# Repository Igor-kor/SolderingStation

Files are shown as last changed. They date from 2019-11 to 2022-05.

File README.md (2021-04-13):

# Паяльный фен
 Основные компоненты:
- Arduino uno
- Операционный усилитель lm358p
- Симистор bt139
- Отопара moc3021
- Источник питаниям 5 вольт и 24 вольта
- OLED дисплей I2C SSD1306
- Энкодер 
- irfz44n для управления скоростью потока воздуха
- ltv814 (2) оптопара для определения перехода через 0, и (для этого можно заменить на ltv817) для включения irfz44n

Используемые библиотеки:
- для дисплея https://github.com/olikraus/u8g2
- библиотека пид регулятора https://playground.arduino.cc/Code/PIDLibrary/
- ускоренное ядро ардуино https://github.com/AlexGyver/GyverCore

Полезная информация
- по настройке коэфициентов пид регулятора http://lazysmart.ru/osnovy-avtomatiki/nastrojka-pid-regulyatora/
- дискретный регулятор мощности (теория, как в итоге должно работать) https://www.qrz.ru/schemes/contribute/digest/bp169.shtml

В собраном виде
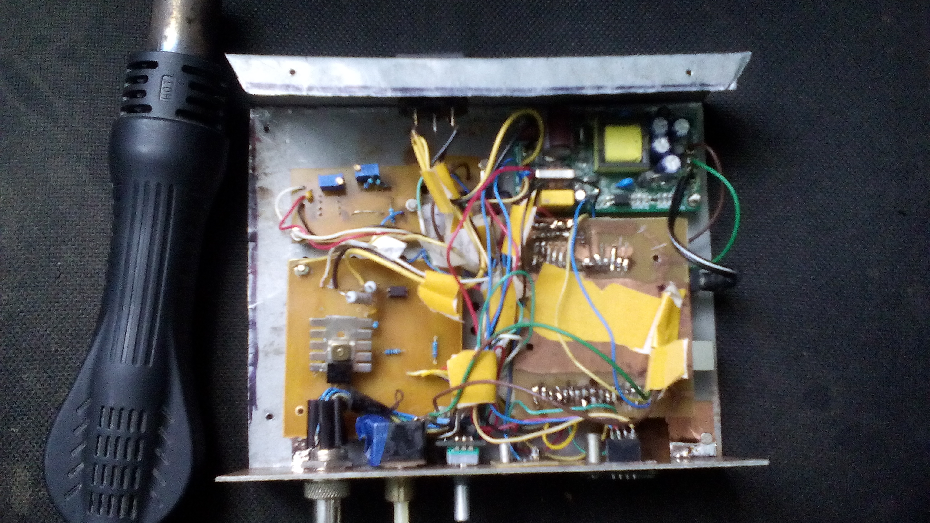
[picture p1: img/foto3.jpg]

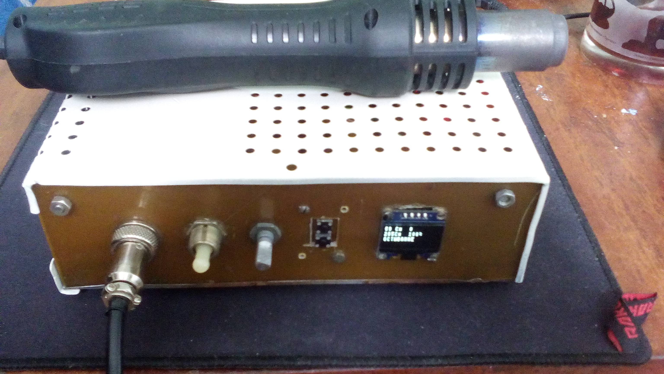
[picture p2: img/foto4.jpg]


Для правильной регулировки написал программу на C# показывающую график https://github.com/Igor-kor/ArduinoDiagramm
- Пример
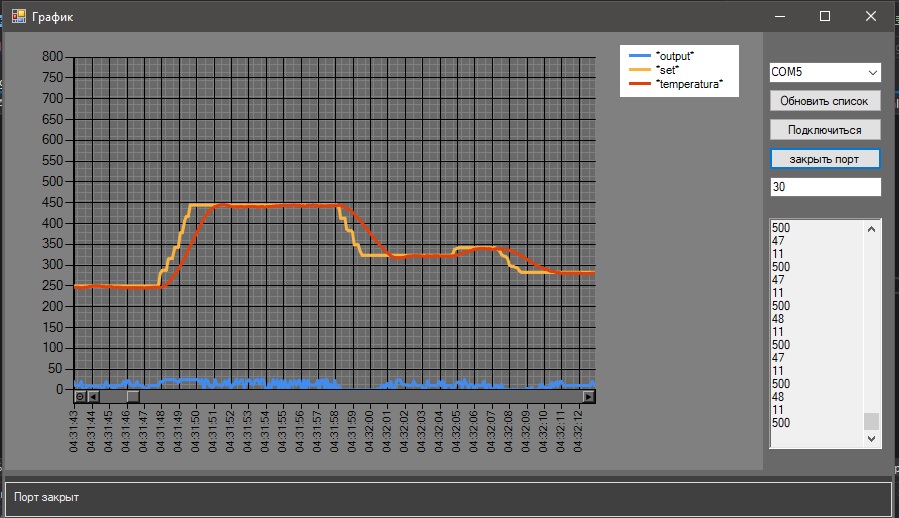
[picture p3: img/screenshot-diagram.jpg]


Схемы
- Определение перехода через 0
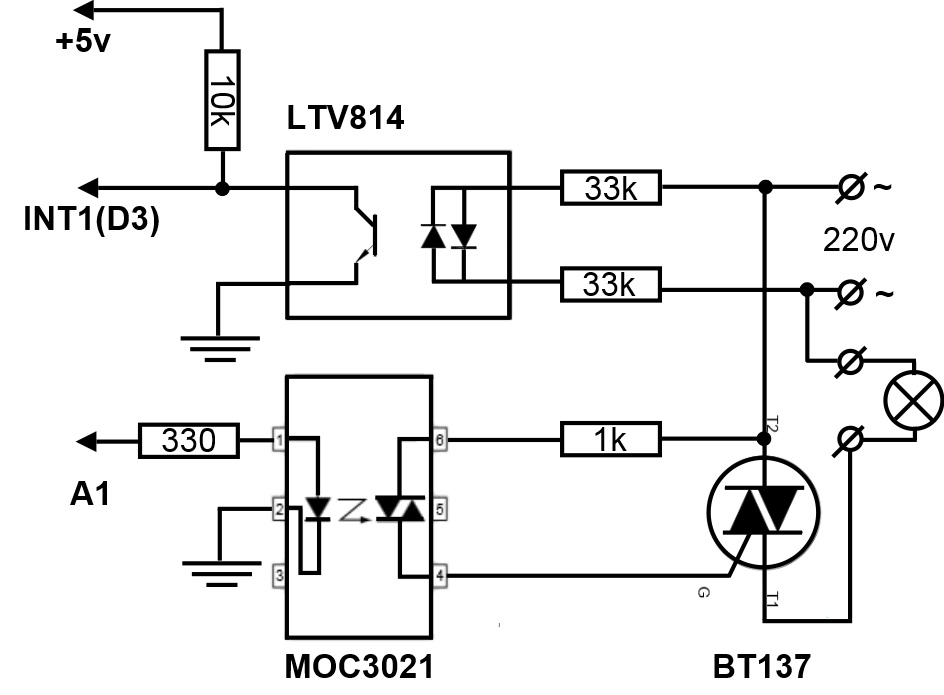
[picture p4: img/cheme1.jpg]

- Управление турбиной фена
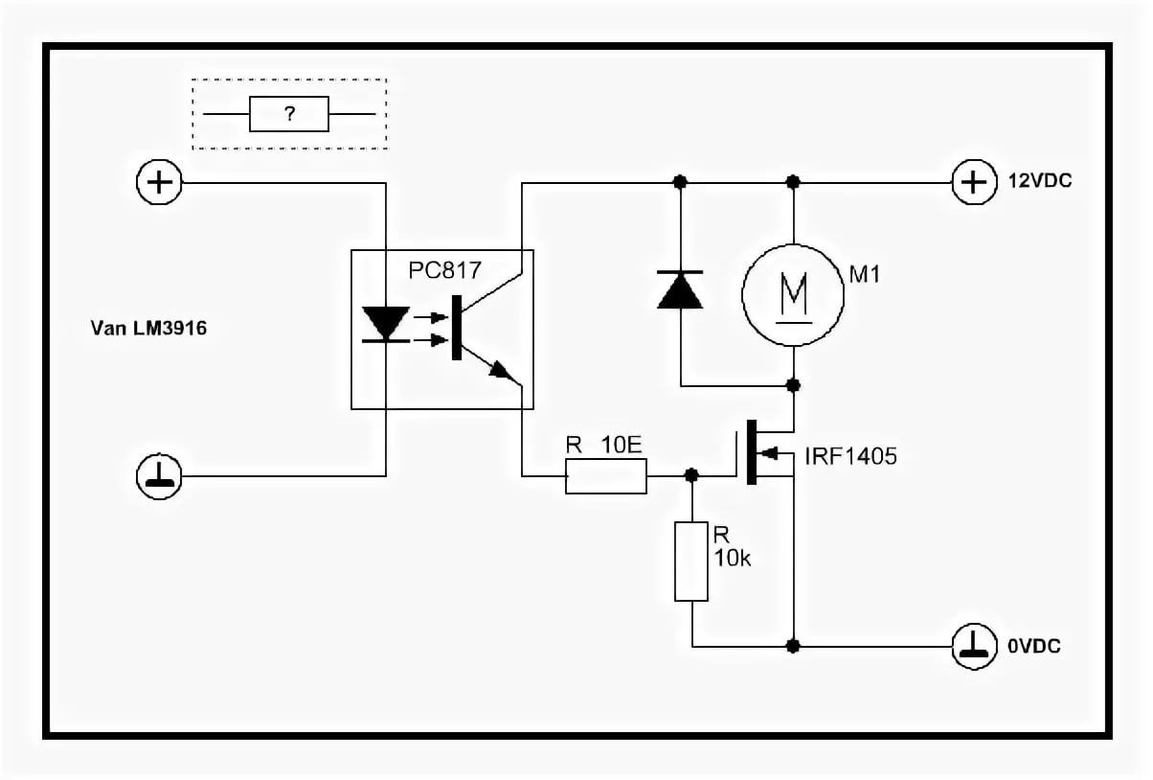
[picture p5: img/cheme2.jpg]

- Усилитель для термопары
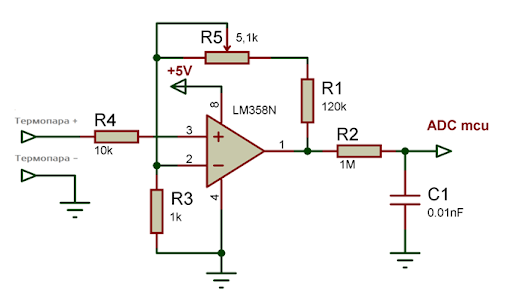
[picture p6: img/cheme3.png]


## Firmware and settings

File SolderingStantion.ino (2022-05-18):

#include <Arduino.h>
#include <U8g2lib.h>

//#define DEBAGSERIAL
//#define DEBAGPIDSERIAL
// Language and font
#include "u8x8_font_ikor.h"
#include "rus.h"
//#include "eng.h"

#include "Thermofan.h"

U8X8_SSD1306_128X32_UNIVISION_HW_I2C u8x8(/* clock=*/ SCL, /* data=*/ SDA, /* reset=*/ U8X8_PIN_NONE);
unsigned long lastTickEncoder;
bool encDirection = 0;
int encCounter = 0;
bool echoEncoder = true;
bool state0, lastState, turnFlag = false;
//uint32_t mil = 0; //текущие милисекунды для вывода на экран
int countzerocross = 0;
int warmcount = 10;
bool statewarm = false;
bool oldstatewarm = false;
// PID
double KP = 7, KI = 5, KD = 0.1;
Thermofan* thermofan1;

void setup() {
  Serial.begin(9600);
#ifdef DEBAGSERIAL
  Serial.println("Setup SolderingStantion.ino");
#endif
  u8x8.begin();
  u8x8.setPowerSave(0);
  u8x8.setFont(u8x8_font_ikor);
  thermofan1 =  new Thermofan();
  attachInterrupt(1, Thermofan::attachCrossZero, FALLING);
  attachInterrupt(0, Thermofan::attachEncoder, CHANGE);

  // инициализация Timer2
    cli(); // отключить глобальные прерывания
    TCCR2A = 0; // установить TCCR1A регистр в 0
    TCCR2B = 0;

    // включить прерывание Timer2 overflow:
    TIMSK2 = (1 << TOIE2);
    // Установить CS10 бит так, чтобы таймер работал при тактовой частоте:
    TCCR2B |= (1 << CS10);
    sei(); // включить глобальные прерывания
#ifdef DEBAGSERIAL
  Serial.println("end Setup SolderingStantion.ino");
#endif
}

ISR(TIMER2_OVF_vect)
{
   Thermofan::attachFun();
}

void loop() {
  #ifdef DEBAGSERIAL
  Serial.println("Loop SolderingStantion.ino");
#endif 
  thermofan1->loopth();
    #ifdef DEBAGSERIAL
  Serial.println("End Loop SolderingStantion.ino");
#endif
}

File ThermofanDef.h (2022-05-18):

#ifndef THERMOFANDEF_H
#define THERMOFANDEF_H

#define VERSION "1.4.4"

//Максимальная температура на потенциометре
#ifndef TEMP_MAX
#define TEMP_MAX 600
#endif

//Температура при достижении которой отключится нагрев(для аварийного охлаждения);
#ifndef TEMP_MAX_OFF
#define TEMP_MAX_OFF 600
#endif

//Температура после которой фен снова начнет свою работу после аварийного охлаждения
#ifndef TEMP_MIN_ON
#define TEMP_MIN_ON 80
#endif

// Время вывода мс(вывод на дисплей сильно замедляет ардуину)
#ifndef TIME_ECHO
#define TIME_ECHO 100
#endif

// примерно 500 тиков совершает между переходом через 0
#ifndef WARMTICK
#define WARMTICK 500
#endif

// для энкодера
#ifndef ENC_LEFT
#define ENC_LEFT 1
#endif

#ifndef ENC_RIGHT
#define ENC_RIGHT 0
#endif

#ifndef MILLIS_CHANGE_DIRECTION
#define MILLIS_CHANGE_DIRECTION 100
#endif

// пин энкодера
#ifndef ENC_A
#define ENC_A 2
#endif

// пин энкодера
#ifndef ENC_B
#define ENC_B 4
#endif

// тип энкодера, 0 или 1
#ifndef ENC_TYPE
#define ENC_TYPE 1
#endif

// Пин термопары(операционного усилителя)
#define THERMOCOUPLE_PIN A0
// Пин оптопары нагрева фена
#define OPTRON_PIN 9
#define SPEED_FAN_PIN 5

#endif

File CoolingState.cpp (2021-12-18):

#include "State.h"
#include "Thermofan.h"
#include "CoolingState.h"
#include "WarmingState.h"
#include "WaitingState.h"
#include "SettingState.h"

extern U8X8_SSD1306_128X32_UNIVISION_HW_I2C u8x8;
extern unsigned long lastTickEncoder;
extern bool encDirection;
extern int encCounter;
extern bool echoEncoder;
extern bool state0, lastState, turnFlag;
extern int countzerocross;
extern int warmcount;
extern bool statewarm;
extern bool oldstatewarm;

CoolingState::CoolingState(Thermofan* context) : State(context) {
#ifdef DEBAGSERIAL
  Serial.println("CoolingState::CoolingState");
#endif
  u8x8.clearLine(2);
  context->echoDisplay("\x9e\xa1\xa2\xab\x92\x90\x9d\x98\x95", 2, 0);
}

void CoolingState::loop() {
#ifdef DEBAGSERIAL
  Serial.println(" CoolingState::loop()");
#endif
  // если температура меньше 50 градусов то перейдем в состояние ожидания
  if (context->Input < 50) {
    context->speedfan = context->echospeedfan;
    echoEncoder = true;
    context->SetState(new WaitingState(context));
    return;
  }
  // если нагрев включили то переходим в состояние нагрева
  if (!context->hermeticContactState) {
    context->speedfan = context->echospeedfan;
    echoEncoder = true;
    context->SetState(new WarmingState(context));
    return;
  }
  warmcount = 0;
  if(context->speedfan != 100) {
     echoEncoder = true;
  }
  context->speedfan = 100;
}

CoolingState::~CoolingState() {
}

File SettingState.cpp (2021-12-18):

#include "State.h"
#include "Thermofan.h"
#include "CoolingState.h"
#include "WarmingState.h"
#include "WaitingState.h"
#include "SettingState.h"

extern U8X8_SSD1306_128X32_UNIVISION_HW_I2C u8x8;
extern unsigned long lastTickEncoder;
extern bool encDirection;
extern int encCounter;
extern bool echoEncoder;
extern bool state0, lastState, turnFlag;
extern int countzerocross;
extern int warmcount;
extern bool statewarm;
extern bool oldstatewarm;
extern double KP,KI,KD;

SettingState::SettingState(Thermofan* context) : State(context) {
#ifdef DEBAGSERIAL
  Serial.println("WaitingState::WaitingState");
#endif
  u8x8.clearLine(2);
  context->echoDisplay(S_SETTING, 2, 0);
  this->oldButtonChange = context->encButtonChange;
}
void SettingState::loop() {
#ifdef DEBAGSERIAL
  Serial.println("SettingState::loop");
#endif
  // если нагрев включили то переходим в состояние нагрева
  if (!context->hermeticContactState) {
    context->speedfan = context->echospeedfan;
    context->SetState(new WarmingState(context));
    echoEncoder = true;
    return;
  }
  warmcount = 0;
  if (context->speedfan > 0) {
    echoEncoder = true;
  }
  context->speedfan = 100;
}

void SettingState::encoder() {
  if (context->encButtonChange != this->oldButtonChange) {
    this->oldButtonChange = context->encButtonChange;
    this->Ksave++;
    if(this->Ksave>2)
      this->Ksave=0;
  }  
   u8x8.clearLine(3);
  switch(this->Ksave){
    case 0:
        KP += encCounter/100.0;
        context->echoDisplay(String("P"), 3, 7);
        context->echoDisplay(String(KP,3), 3, 0);
      break;
    case 1:
        KI += encCounter/100.0;
        context->echoDisplay(String("I"), 3, 7);
        context->echoDisplay(String(KI,3), 3, 0);
      break;
    case 2:
        KD += encCounter/100.0;
        context->echoDisplay(String("D"), 3, 7);
        context->echoDisplay(String(KD,3), 3, 0);
      break;
  }
}

SettingState::~SettingState() {
}

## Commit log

2018-02-18 не рабочая плата, и прошивка не доработана инит коммит
    [stantion.sch]
2018-02-18 начал переделывать схему
2018-03-19 сделал класс термофена
2018-05-22 немного отрефакторил
2018-09-17 добаил реле на 4 пин
2019-11-08 добавил lcd экран и немного отрефакторил
2019-11-09 небольшие правки
2019-11-10 вынес класс в отдельный файл, оптимизировал вывод, вернул старые значения пид
2019-11-12 пофиксил нагрев во время вывода на дисплэй
2019-11-12 тест обновления экрана только при изменении(не работает т.к. экран очищается спустя секнду)
2019-11-12 вернул как было и убрал автообновление экрана
2019-11-12 пофиксил названия класса и инклуда
2019-11-12 рефакторинг и фикс бага при отключении нагрева this->warmingFan
2019-11-12 добавил ошибки и обработчик на ошибку 1( перегрев фена)
2019-11-12 изменил название stantion.ino на SolderingStation.ino
2019-11-12 изменил описание в readme
2019-11-13 переименовал на правильное название
2019-11-18 удалил старые схемы, добавил новые,для нагрева работает на текущий момент(без определения перехода через 0), вторую схему(для оу) не проверял
    [stantion.sch]
2019-11-18 добаивл схему для определения перехода через 0(не уверен что разводка по этой схеме)
2019-12-18 добавил оптопару для определения перехода фазы через 0, переделал нагрев фена(тест)
2020-01-06 сделал схему для управлением потока воздуха, и в коде для теста, нужен потенциометр
2020-02-09 обновил рэдми
2020-02-14 сделал рабочий энкодер
2020-02-14 рефакторинг
2020-02-15 сделал кнопку энкодера и смену выбора значений(температура-скорость потока)
2020-02-15 сделал управление потоком воздуха с энкодера
2020-02-15 пофиксил управление потоком воздуха
2020-02-20 Сделал энкодер более стабильным, сделал сохранения в eeprom установленных значений при нажатии на энкодер
2020-02-22 поменял направление энкодера
2020-03-02 исправлены ошибки в разводке плат, добавлена схема управления вентилятором
2020-03-02 изменил методику нагрева, частично пофиксил баг при включении, изменил пид коэфициенты
2020-03-03 добавил отдельную кнопку сохранения
2020-03-05 добавил кнопки и плату для них
2020-06-24 мелкие правки
2020-07-24 добавил корректировку температуры,присутствует проблема - после 370 градусов, фен начинает бесконтрольно нагреваться до предела
2020-07-27 на + термапары припаял резистор 10 КОм, сделал калибровку пида, уменьшил интервал просчета пида, изменил корректировку, сделал больше число для регулировки(WARMTICK)
2020-07-28 создал папку img, добавил изображения, обновил редми
2021-03-09 вынес пины в макросы, оптимизировал функцию нагрева, немного оптимизировал вывод на дисплей(нужно еще больше оптимизировать)
2021-03-10 переделал функцию энкодера, при быстром вращении теперь больше прибавляет
2021-03-10 нужно исправить баг с нагревом
    [ThermofanDef.h]
2021-03-11 перенастраиваю пид, сделал остывание фена и выключение турбины
2021-03-29 вынес все классы в отдельные файлы, реализацию в cpp файлы, делаю шаблон состояния
2021-04-08 промежуточный коммит
2021-04-13 доделал состояния, необходимо пофиксить баг с переходом, вполне рабочий коммит
2021-04-13 немного пофиксил баг, но не до конца
2021-04-13 чуть лучше чем было но баг с зависанием остался
2021-04-14 fix display cirilic text
    [CoolingState.cpp, SolderingStantion.ino, WaitingState.cpp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]
2021-04-14 переделываю энкодер, есть баг с сохранением скорости фена
2021-08-11 пофиксил баг в выводе скоросте фена, баг в сохранении скорости фена, баг в коде в присвоении и в условии
2021-08-11 пофиксил баг с охлаждением
2021-08-11 переделал изменение скорости фена, и пофиксил баг с сохранением скорости
2021-08-11 убрал лишнее
2021-12-17 Изменил переменные для времени
2021-12-17 Пофиксил баг при долгом ожидании
2021-12-18 add class settingstate, add version for reset eeprom
    [CoolingState.cpp, SettingState.cpp, SolderingStantion.ino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]
2021-12-18 Сделал настройки, для входа зажать кнопку сохранения и перезапустить
2022-05-18 переделал функцию нагрева, использовав timer2, теперь работает как нормальный диммер
2022-06-09 add kicad scheme
    [SolderingStation.kicad_pcb, SolderingStation.kicad_sch]
